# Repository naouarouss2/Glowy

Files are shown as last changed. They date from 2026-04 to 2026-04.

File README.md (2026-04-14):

# Glowy
## What is it ? 💡
Glowy is a 20*15 neopixel matrix running the WLED firmware.
## Why did I make it ? 🛠️
I have always been fond of mood and party lighting, and I think that the idea of a matrix combines both of them.
## Features ✅
- 90W Total output
- WiFi connectivity
- More than 100 lighting effect
- Sound reactive effects
## 3D Design 🎨
|Full Design|3D Printed Parts|Laser-cut Parts|Commercial Parts|
|-|-|-|-|
|||||
## Firmware 💾
For this project, I will be using the **[WLED firmware](https://kno.wled.ge/)**
## Wiring diagram 🔌
Untitled Sketch_bb
Please note that each strip is 20 LEDs long.
## Credits ❤️
Made by **Oussama NAOUAR**

Made as part of the **Hack Club Stasis** program asking for a grant.

Total work time logged : 23.4h
## License 🔓
This project is put opensource.

Building as is, is allowed.

Remixing is also allowed, as long as the original project is linked and credited.
## BOM 💵
The prices below were **converted from TND to USD** based on the **conversion rates between 08-03-2026 and 09-04-2026**
|Name |Purpose |Quantity|Total Cost (USD)|Link |Distributor|
|---|---|---|---|---|---|
|M4 Nut |Mount everything to the back plate |24 |0.05 |https://cothings.net/products/ecrou-hexagonal-en-acier-inoxydable-304-m4 |Cothings |
|M3 Nut |Mount the spacers to the front plate |24 |0.09 |https://cothings.net/products/ecrou-hexagonal-en-acier-inoxydable-304-m3 |Cothings |
|Laser-cut parts |The frame of the project |1 |6.09 | |FabLab |
|M3*20 Screws |Mount spacers to the front plate |24 |0.07 |https://cothings.net/products/vis-a-tete-cylindrique-m3x20mm |Cothings |
|M4*16 Screws |Mount everything to the back plate |24 |0.07 | |BricoMode  |
|M2*10 Screw |Mount the diffuser grids to the mounting plate |48 |0.07 |https://cothings.net/products/copie-de-vis-a-tete-fraisee-m4x10?_pos=29&_sid=6fd5a4ea5&_ss=r |Cothings |
|5V 20A Power supply |Provide power to the matrix |1 |13.48 |https://cothings.net/products/alimentation-5v-20a-100w |Cothings |
|WS2812B 5M 60LED/M RGB Strip|RGB LEDS to light up the matrix |1 |25.28 |https://2btrading.tn/afficheurs-led-lcd/7301-ruban-ws2812b-addressable-led-rgb-5v-60leds-5050-5m.html|2B Trading |
|MAX4466 Microphone Module |It will enable the matrix to react to sounds |1 |4.22 |https://cothings.net/products/micro-electret-amplifier-max4466-avec-gain-reglable |Cothings |
|ESP32-D1 |The brain of this project. It will be the LED matrix controller.|1 |7.90 |https://seli.tn/product/mini-esp32-d1-mini-carte-de-developpement-interface-micro-usb/ |Seli |

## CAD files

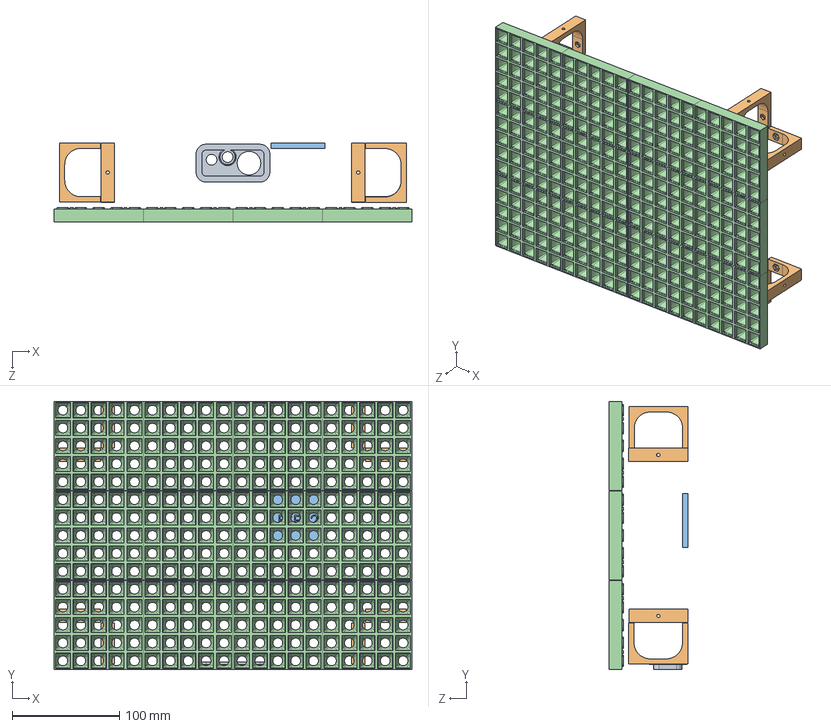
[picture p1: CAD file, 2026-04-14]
CAD/Source Files/Assembly.SLDASM
333.2 x 249.9 x 73.6 mm
Grid x 12
ESP32
Support x 8
Bottom Electronics Mount

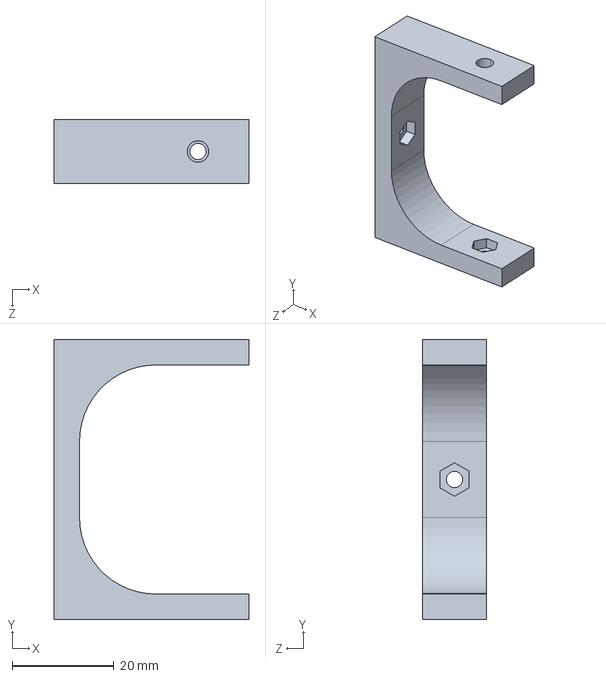
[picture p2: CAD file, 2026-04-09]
CAD/3D Printed Parts/Support.STEP
38.3 x 55.0 x 12.5 mm

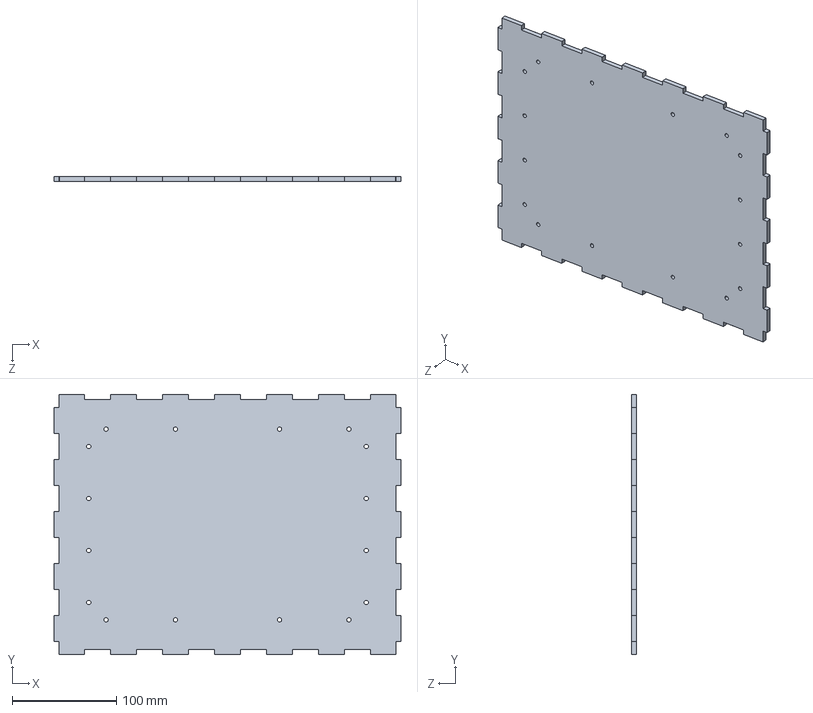
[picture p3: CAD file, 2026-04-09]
CAD/Laser-Cut Parts/STEP/Back Plate.STEP
333.3 x 249.9 x 5.00 mm

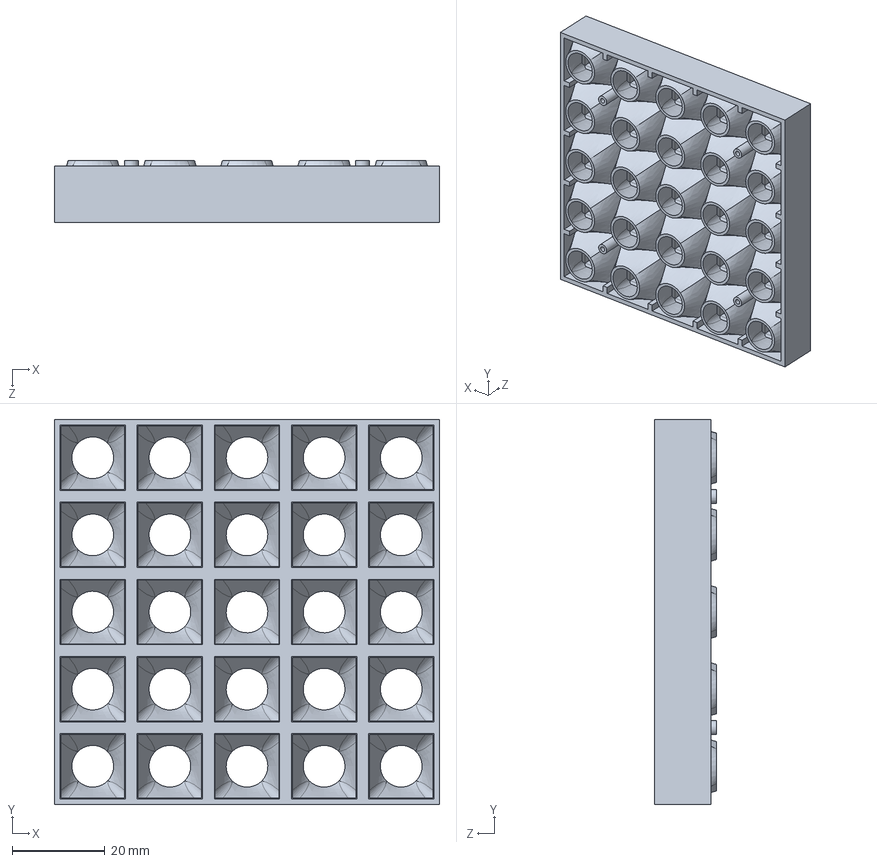
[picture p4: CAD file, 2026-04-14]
CAD/Source Files/Grid.SLDPRT
83.2 x 83.2 x 13.4 mm

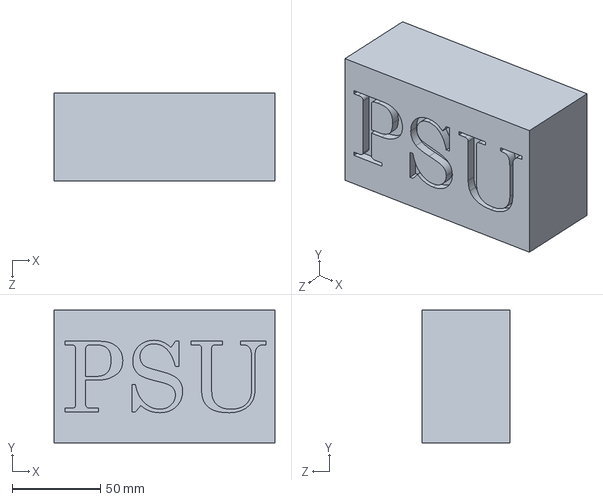
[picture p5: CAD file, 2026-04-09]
CAD/Testing and Sample Models/PSU.STEP
125.0 x 75.0 x 50.0 mm

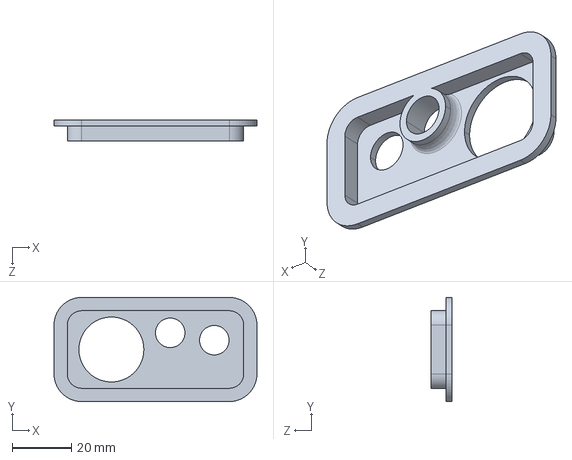
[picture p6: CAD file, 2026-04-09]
CAD/3D Printed Parts/Bottom Electronics Mount.STEP
68.8 x 35.3 x 7.00 mm

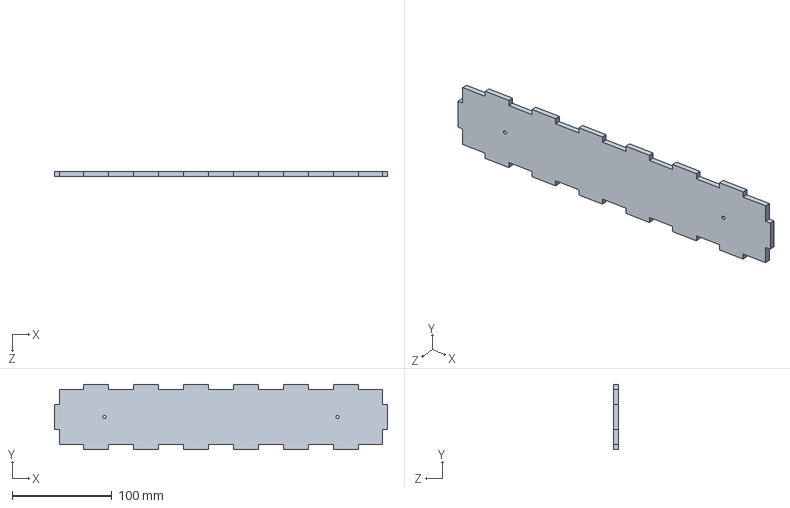
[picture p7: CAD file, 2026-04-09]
CAD/Laser-Cut Parts/STEP/Top.STEP
333.3 x 65.2 x 5.00 mm

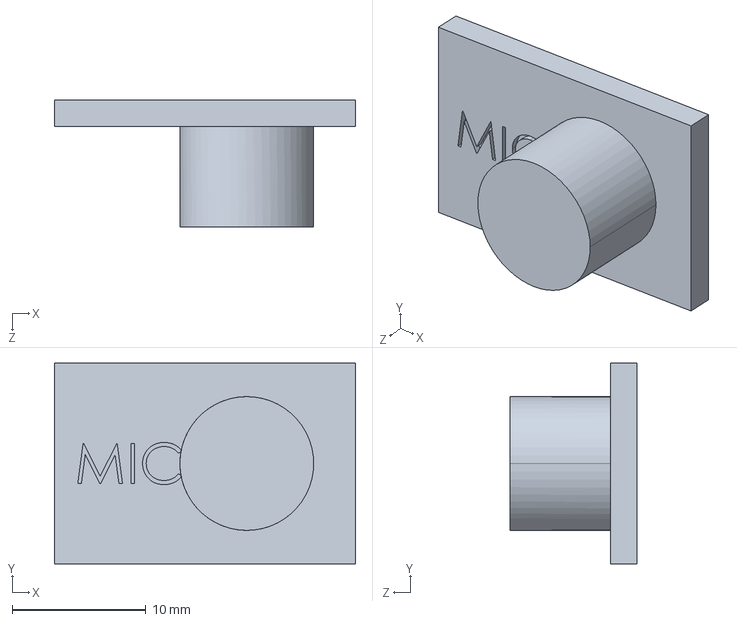
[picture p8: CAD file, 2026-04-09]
CAD/Testing and Sample Models/MIC.STEP
22.5 x 15.0 x 9.50 mm

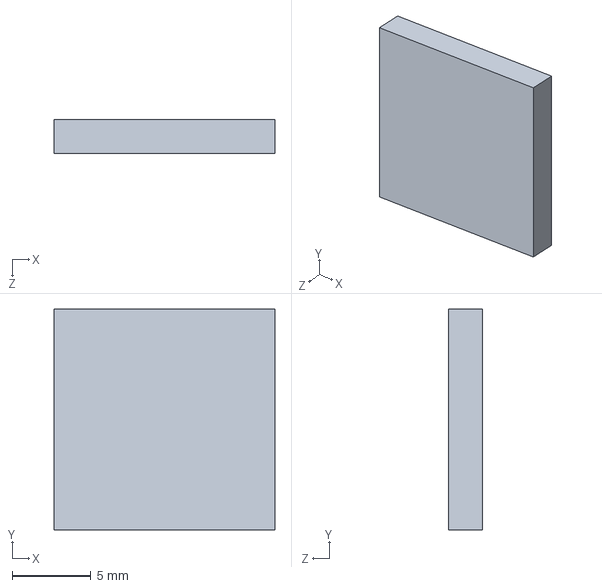
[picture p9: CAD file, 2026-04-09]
CAD/3D Printed Parts/Diffuser.STEP
14.1 x 14.1 x 2.14 mm

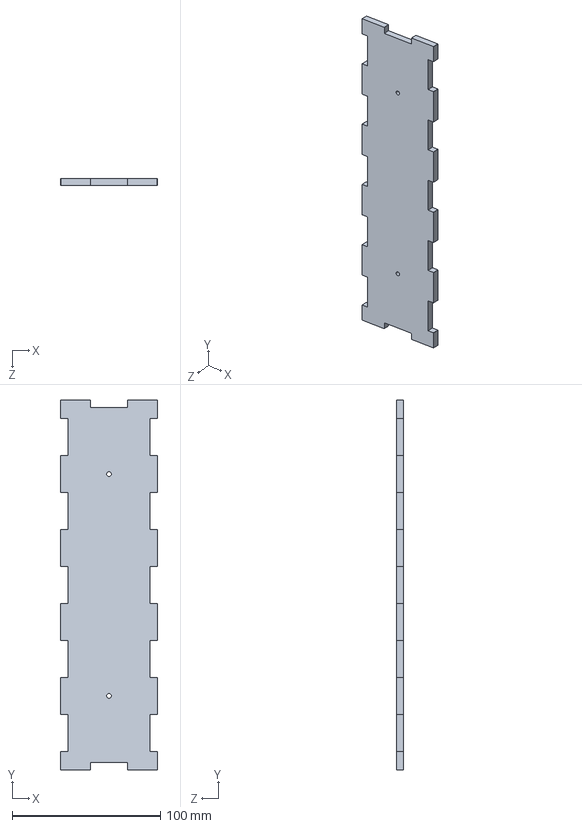
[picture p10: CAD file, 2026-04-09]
CAD/Laser-Cut Parts/STEP/Left.STEP
65.2 x 249.9 x 5.00 mm

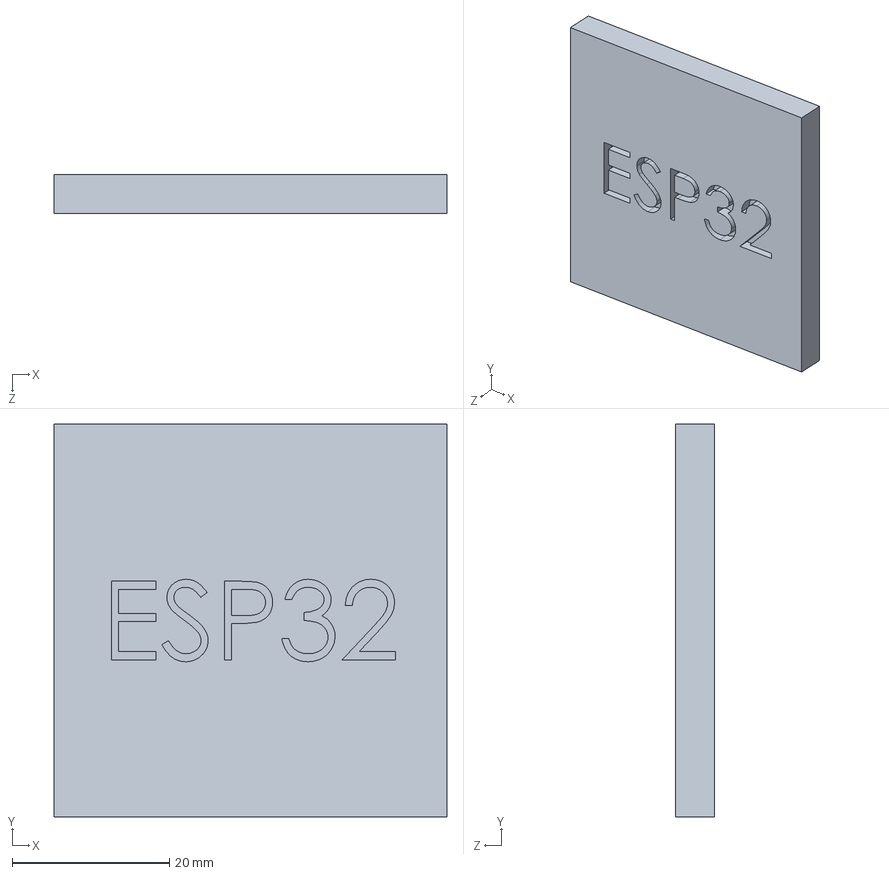
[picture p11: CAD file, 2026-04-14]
CAD/Source Files/ESP32.SLDPRT
50.0 x 50.0 x 5.00 mm

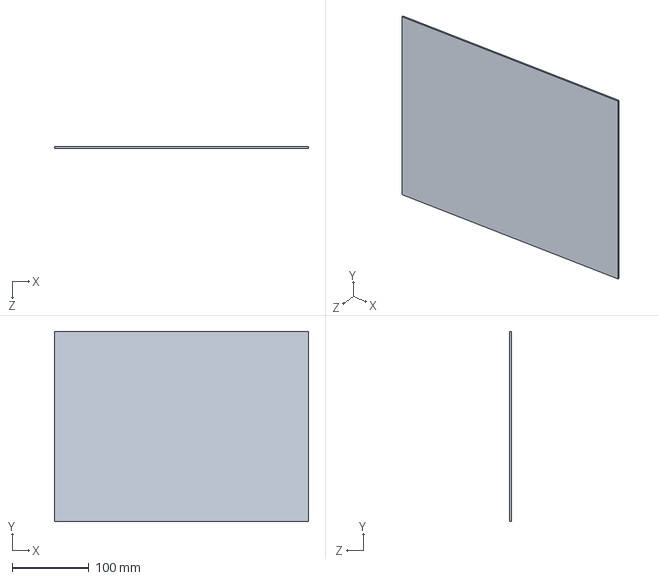
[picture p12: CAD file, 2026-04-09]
CAD/Testing and Sample Models/Diffuser test model.STEP
331.4 x 248.1 x 2.14 mm

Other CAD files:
CAD/Source Files/Bottom Electronics Mount.SLDPRT
CAD/3D Printed Parts/Grid.STEP
CAD/Laser-Cut Parts/STEP/Right.STEP
CAD/Source Files/Support.SLDPRT
CAD/Testing and Sample Models/ESP32.STEP
CAD/Laser-Cut Parts/STEP/Mounting Plate.STEP
CAD/Laser-Cut Parts/DXF/Back Plate.DXF
CAD/Laser-Cut Parts/DXF/Bottom.DXF
CAD/Laser-Cut Parts/DXF/Left.DXF
CAD/Laser-Cut Parts/DXF/Mounting Plate.DXF
CAD/Laser-Cut Parts/DXF/Right.DXF
CAD/Laser-Cut Parts/DXF/Top.DXF
CAD/Laser-Cut Parts/STEP/Bottom.STEP
CAD/Source Files/Back Plate.SLDPRT
CAD/Source Files/Bottom.SLDPRT
CAD/Source Files/Diffuser test model.SLDPRT
CAD/Source Files/Diffuser.SLDPRT
CAD/Source Files/Left.SLDPRT
CAD/Source Files/MIC.SLDPRT
CAD/Source Files/Mounting Plate.SLDPRT
CAD/Source Files/PSU.SLDPRT
CAD/Source Files/Right.SLDPRT
CAD/Source Files/Top.SLDPRT

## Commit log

2026-04-09 Add ReadMe
    [Back Plate.STEP, Bottom.STEP, Grid.STEP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]
2026-04-09 Improve README formatting and add BOM information
    Updated the README to enhance formatting and add BOM details.
